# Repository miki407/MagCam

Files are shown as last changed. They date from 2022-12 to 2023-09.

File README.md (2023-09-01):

# MagCam

## Introduction
MagCam is a project that aims to bring a better way of teaching principles of magnetism in a classroom environment. Using this device we hope that students will be more engaged in learning about various topics regarding magnetism as well as electromagnetism. During the process of making this device we looked for a way to improve on the traditional methods of displaying magnetic fields.  

## Comparison with traditional methods

|  Method | Presentation | Versatility | Sensitivity | Polarity | Extra Notes |
|---|---|---|---|---| --- |
| MagCam  | The results can be displayed on a projector | Very versatile in terms of experiments that can be performed | Sensitive to small magnetic fields but limited by the ADC and pre-amp | Has the ability to distinguish between **north** and **south** poles | Can record the data captured
| Iron Dust | Limited number of students can see the results at one time | Number of experiments that can be performed is limited | Only sensitive to strong magnetic fields. Better results can be achieved if particles are suspended in liquid | Doesn't have a way to clearly distinguish between 2 poles | Can stick to the magnets and damage other equipment in the lab |  
| [Flux Detector](https://www.supermagnete.de/eng/school-magnets/flux-detector-small_M-04) | Limited number of students can see the results at one time | Number of experiments that can be performed is sufficient for basic needs | Only sensitive to strong magnetic fields | Doesn't have a way to clearly distinguish between 2 poles |
| Compass array | Limited number of students can see the results at one time |  Very versatile in terms of experiments that can be performed | Sensitive to weak magnetic fields | Has the ability to distinguish between **north** and **south** poles | The device is composed of mechanical compasses and thus needs to be kept horizontal |
| Ferro fluid | Limited number of students can see the results at one time | Number of experiments that can be performed is sufficient for basic needs | Only sensitive to strong magnetic fields | Doesn't have a way to clearly distinguish between 2 poles | Has the possibility to damage other equipment and is hard to clean |
| Virtual demonstration | The results can be displayed on a projector | Any experiment that can be virtually modeled can be performed | The most sensitive option | Has the ability to distinguish between **north** and **south** poles | Requires special training in use of simulation software. It can take a long time for results to be ready. This method doesn't measure magnetic fields and only **simulates** them |

## Basic overview 
MagCam uses 256 hall effect sensors to determine the strength of the magnetic field over a detection area of 110x110 mm. This data is read and sent to the computer for further processing by and esp32 microcontroller. The data is processed and displayed on the computer using an app that was written specifically for this device.

## App
The app reads the values sent by the esp32 and decodes them into individual frames. This data is then calibrated using a baseline value for each sensors. This improves the reading accuracy and allows for less noisy results. In case large gain is used the values received from the device can be averaged. This allows for even less noisy results. 
The app also has a feature that recreates the magnetic field lines from the change in local magnet field strength.
> App is still in development  and more features are planned in the future. There are also plans to improve the gui

## Files
all the files can be found [here](https://github.com/miki407/MagCam)

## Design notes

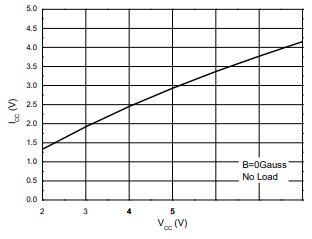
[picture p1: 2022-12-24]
Images/Vcc-Icc_graph_AH49HSC.JPG

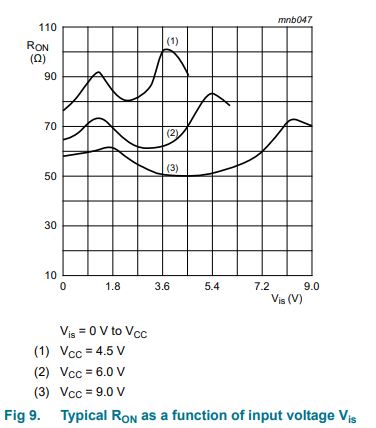
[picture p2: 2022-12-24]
Images/74HC4067_Ron-Vis.JPG

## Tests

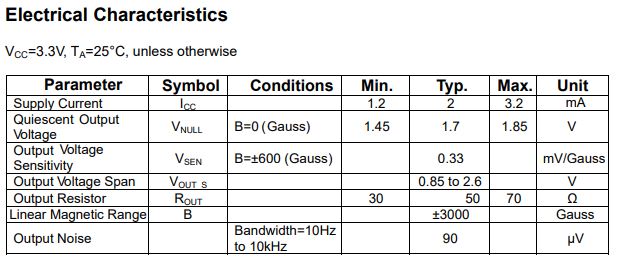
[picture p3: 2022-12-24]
Images/Electrical-characteristic_table.JPG

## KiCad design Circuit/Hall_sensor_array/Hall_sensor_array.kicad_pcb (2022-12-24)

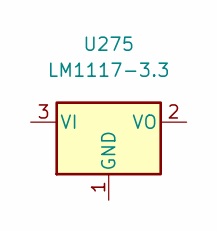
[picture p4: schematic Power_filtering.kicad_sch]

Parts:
U275: LM1117-3.3

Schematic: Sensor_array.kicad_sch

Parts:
C1, C2, C3, C4, C5, C6, C7, C8, C9, C10, C11, C12, C13, C14, C15, C16, C17, C18, C19, C20, C21, C22, C23, C24, C25, C26, C27, C28, C29, C30, C31, C32, C33, C34, C35, C36, C37, C38, C39, C40, C41, C42, C43, C44, C45, C46, C47, C48, C49, C50, C51, C52, C53, C54, C55, C56, C57, C58, C59, C60, C61, C62, C63, C64, C65, C66, C67, C68, C69, C70, C71, C72, C73, C74, C75, C76, C77, C78, C79, C80, C81, C82, C83, C84, C85, C86, C87, C88, C89, C90, C91, C92, C93, C94, C95, C96, C97, C98, C99, C100, C101, C102, C103, C104, C105, C106, C107, C108, C109, C110, C111, C112, C113, C114, C115, C116, C117, C118, C119, C120, C121, C122, C123, C124, C125, C126, C127, C128, C129, C130, C131, C132, C133, C134, C135, C136, C137, C138, C139, C140, C141, C142, C143, C144, C145, C146, C147, C148, C149, C150, C151, C152, C153, C154, C155, C156, C157, C158, C159, C160, C161, C162, C163, C164, C165, C166, C167, C168, C169, C170, C171, C172, C173, C174, C175, C176, C177, C178, C179, C180, C181, C182, C183, C184, C185, C186, C187, C188, C189, C190, C191, C192, C193, C194, C195, C196, C197, C198, C199, C200, C201, C202, C203, C204, C205, C206, C207, C208, C209, C210, C211, C212, C213, C214, C215, C216, C217, C218, C219, C220, C221, C222, C223, C224, C225, C226, C227, C228, C229, C230, C231, C232, C233, C234, C235, C236, C237, C238, C239, C240, C241, C242, C243, C244, C245, C246, C247, C248, C249, C250, C251, C252, C253, C254, C255, C256: 100p; C_0603_1608Metric
U1, U2, U3, U4, U5, U6, U7, U8, U9, U10, U11, U12, U13, U14, U15, U16, U17, U18, U19, U20, U21, U22, U23, U24, U25, U26, U27, U28, U29, U30, U31, U32, U33, U34, U35, U36, U37, U38, U39, U40, U41, U42, U43, U44, U45, U46, U47, U48, U49, U50, U51, U52, U53, U54, U55, U56, U57, U58, U59, U60, U61, U62, U63, U64, U65, U66, U67, U68, U69, U70, U71, U72, U73, U74, U75, U76, U77, U78, U79, U80, U81, U82, U83, U84, U85, U86, U87, U88, U89, U90, U91, U92, U93, U94, U95, U96, U97, U98, U99, U100, U101, U102, U103, U104, U105, U106, U107, U108, U109, U110, U111, U112, U113, U114, U115, U116, U117, U118, U119, U120, U121, U122, U123, U124, U125, U126, U127, U128, U129, U130, U131, U132, U133, U134, U135, U136, U137, U138, U139, U140, U141, U142, U143, U144, U145, U146, U147, U148, U149, U150, U151, U152, U153, U154, U155, U156, U157, U158, U159, U160, U161, U162, U163, U164, U165, U166, U167, U168, U169, U170, U171, U172, U173, U174, U175, U176, U177, U178, U179, U180, U181, U182, U183, U184, U185, U186, U187, U188, U189, U190, U191, U192, U193, U194, U195, U196, U197, U198, U199, U200, U201, U202, U203, U204, U205, U206, U207, U208, U209, U210, U211, U212, U213, U214, U215, U216, U217, U218, U219, U220, U221, U222, U223, U224, U225, U226, U227, U228, U229, U230, U231, U232, U233, U234, U235, U236, U237, U238, U239, U240, U241, U242, U243, U244, U245, U246, U247, U248, U249, U250, U251, U252, U253, U254, U255, U256: AH49HSC; SOT-23-3

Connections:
+3.3V: U1.1 (VDD), U2.1 (VDD), U3.1 (VDD), U4.1 (VDD), U5.1 (VDD), U6.1 (VDD), U7.1 (VDD), U8.1 (VDD), U9.1 (VDD), U10.1 (VDD), U11.1 (VDD), U12.1 (VDD), U13.1 (VDD), U14.1 (VDD), U15.1 (VDD), U16.1 (VDD), U17.1 (VDD), U18.1 (VDD), U19.1 (VDD), U20.1 (VDD), U21.1 (VDD), U22.1 (VDD), U23.1 (VDD), U24.1 (VDD), U25.1 (VDD), U26.1 (VDD), U27.1 (VDD), U28.1 (VDD), U29.1 (VDD), U30.1 (VDD), U31.1 (VDD), U32.1 (VDD), U33.1 (VDD), U34.1 (VDD), U35.1 (VDD), U36.1 (VDD), U37.1 (VDD), U38.1 (VDD), U39.1 (VDD), U40.1 (VDD), U41.1 (VDD), U42.1 (VDD), U43.1 (VDD), U44.1 (VDD), U45.1 (VDD), U46.1 (VDD), U47.1 (VDD), U48.1 (VDD), U49.1 (VDD), U50.1 (VDD), U51.1 (VDD), U52.1 (VDD), U53.1 (VDD), U54.1 (VDD), U55.1 (VDD), U56.1 (VDD), U57.1 (VDD), U58.1 (VDD), U59.1 (VDD), U60.1 (VDD), U61.1 (VDD), U62.1 (VDD), U63.1 (VDD), U64.1 (VDD), U65.1 (VDD), U66.1 (VDD), U67.1 (VDD), U68.1 (VDD), U69.1 (VDD), U70.1 (VDD), U71.1 (VDD), U72.1 (VDD), U73.1 (VDD), U74.1 (VDD), U75.1 (VDD), U76.1 (VDD), U77.1 (VDD), U78.1 (VDD), U79.1 (VDD), U80.1 (VDD), U81.1 (VDD), U82.1 (VDD), U83.1 (VDD), U84.1 (VDD), U85.1 (VDD), U86.1 (VDD), U87.1 (VDD), U88.1 (VDD), U89.1 (VDD), U90.1 (VDD), U91.1 (VDD), U92.1 (VDD), U93.1 (VDD), U94.1 (VDD), U95.1 (VDD), U96.1 (VDD), U97.1 (VDD), U98.1 (VDD), U99.1 (VDD), U100.1 (VDD), U101.1 (VDD), U102.1 (VDD), U103.1 (VDD), U104.1 (VDD), U105.1 (VDD), U106.1 (VDD), U107.1 (VDD), U108.1 (VDD), U109.1 (VDD), U110.1 (VDD), U111.1 (VDD), U112.1 (VDD), U113.1 (VDD), U114.1 (VDD), U115.1 (VDD), U116.1 (VDD), U117.1 (VDD), U118.1 (VDD), U119.1 (VDD), U120.1 (VDD), U121.1 (VDD), U122.1 (VDD), U123.1 (VDD), U124.1 (VDD), U125.1 (VDD), U126.1 (VDD), U127.1 (VDD), U128.1 (VDD), U129.1 (VDD), U130.1 (VDD), U131.1 (VDD), U132.1 (VDD), U133.1 (VDD), U134.1 (VDD), U135.1 (VDD), U136.1 (VDD), U137.1 (VDD), U138.1 (VDD), U139.1 (VDD), U140.1 (VDD), U141.1 (VDD), U142.1 (VDD), U143.1 (VDD), U144.1 (VDD), U145.1 (VDD), U146.1 (VDD), U147.1 (VDD), U148.1 (VDD), U149.1 (VDD), U150.1 (VDD), U151.1 (VDD), U152.1 (VDD), U153.1 (VDD), U154.1 (VDD), U155.1 (VDD), U156.1 (VDD), U157.1 (VDD), U158.1 (VDD), U159.1 (VDD), U160.1 (VDD), U161.1 (VDD), U162.1 (VDD), U163.1 (VDD), U164.1 (VDD), U165.1 (VDD), U166.1 (VDD), U167.1 (VDD), U168.1 (VDD), U169.1 (VDD), U170.1 (VDD), U171.1 (VDD), U172.1 (VDD), U173.1 (VDD), U174.1 (VDD), U175.1 (VDD), U176.1 (VDD), U177.1 (VDD), U178.1 (VDD), U179.1 (VDD), U180.1 (VDD), U181.1 (VDD), U182.1 (VDD), U183.1 (VDD), U184.1 (VDD), U185.1 (VDD), U186.1 (VDD), U187.1 (VDD), U188.1 (VDD), U189.1 (VDD), U190.1 (VDD), U191.1 (VDD), U192.1 (VDD), U193.1 (VDD), U194.1 (VDD), U195.1 (VDD), U196.1 (VDD), U197.1 (VDD), U198.1 (VDD), U199.1 (VDD), U200.1 (VDD), U201.1 (VDD), U202.1 (VDD), U203.1 (VDD), U204.1 (VDD), U205.1 (VDD), U206.1 (VDD), U207.1 (VDD), U208.1 (VDD), U209.1 (VDD), U210.1 (VDD), U211.1 (VDD), U212.1 (VDD), U213.1 (VDD), U214.1 (VDD), U215.1 (VDD), U216.1 (VDD), U217.1 (VDD), U218.1 (VDD), U219.1 (VDD), U220.1 (VDD), U221.1 (VDD), U222.1 (VDD), U223.1 (VDD), U224.1 (VDD), U225.1 (VDD), U226.1 (VDD), U227.1 (VDD), U228.1 (VDD), U229.1 (VDD), U230.1 (VDD), U231.1 (VDD), U232.1 (VDD), U233.1 (VDD), U234.1 (VDD), U235.1 (VDD), U236.1 (VDD), U237.1 (VDD), U238.1 (VDD), U239.1 (VDD), U240.1 (VDD), U241.1 (VDD), U242.1 (VDD), U243.1 (VDD), U244.1 (VDD), U245.1 (VDD), U246.1 (VDD), U247.1 (VDD), U248.1 (VDD), U249.1 (VDD), U250.1 (VDD), U251.1 (VDD), U252.1 (VDD), U253.1 (VDD), U254.1 (VDD), U255.1 (VDD), U256.1 (VDD)
GND: C1.2, C2.2, C3.2, C4.2, C5.2, C6.2, C7.2, C8.2, C9.2, C10.2, C11.2, C12.2, C13.2, C14.2, C15.2, C16.2, C17.2, C18.2, C19.2, C20.2, C21.2, C22.2, C23.2, C24.2, C25.2, C26.2, C27.2, C28.2, C29.2, C30.2, C31.2, C32.2, C33.2, C34.2, C35.2, C36.2, C37.2, C38.2, C39.2, C40.2, C41.2, C42.2, C43.2, C44.2, C45.2, C46.2, C47.2, C48.2, C49.2, C50.2, C51.2, C52.2, C53.2, C54.2, C55.2, C56.2, C57.2, C58.2, C59.2, C60.2, C61.2, C62.2, C63.2, C64.2, C65.2, C66.2, C67.2, C68.2, C69.2, C70.2, C71.2, C72.2, C73.2, C74.2, C75.2, C76.2, C77.2, C78.2, C79.2, C80.2, C81.2, C82.2, C83.2, C84.2, C85.2, C86.2, C87.2, C88.2, C89.2, C90.2, C91.2, C92.2, C93.2, C94.2, C95.2, C96.2, C97.2, C98.2, C99.2, C100.2, C101.2, C102.2, C103.2, C104.2, C105.2, C106.2, C107.2, C108.2, C109.2, C110.2, C111.2, C112.2, C113.2, C114.2, C115.2, C116.2, C117.2, C118.2, C119.2, C120.2, C121.2, C122.2, C123.2, C124.2, C125.2, C126.2, C127.2, C128.2, C129.2, C130.2, C131.2, C132.2, C133.2, C134.2, C135.2, C136.2, C137.2, C138.2, C139.2, C140.2, C141.2, C142.2, C143.2, C144.2, C145.2, C146.2, C147.2, C148.2, C149.2, C150.2, C151.2, C152.2, C153.2, C154.2, C155.2, C156.2, C157.2, C158.2, C159.2, C160.2, C161.2, C162.2, C163.2, C164.2, C165.2, C166.2, C167.2, C168.2, C169.2, C170.2, C171.2, C172.2, C173.2, C174.2, C175.2, C176.2, C177.2, C178.2, C179.2, C180.2, C181.2, C182.2, C183.2, C184.2, C185.2, C186.2, C187.2, C188.2, C189.2, C190.2, C191.2, C192.2, C193.2, C194.2, C195.2, C196.2, C197.2, C198.2, C199.2, C200.2, C201.2, C202.2, C203.2, C204.2, C205.2, C206.2, C207.2, C208.2, C209.2, C210.2, C211.2, C212.2, C213.2, C214.2, C215.2, C216.2, C217.2, C218.2, C219.2, C220.2, C221.2, C222.2, C223.2, C224.2, C225.2, C226.2, C227.2, C228.2, C229.2, C230.2, C231.2, C232.2, C233.2, C234.2, C235.2, C236.2, C237.2, C238.2, C239.2, C240.2, C241.2, C242.2, C243.2, C244.2, C245.2, C246.2, C247.2, C248.2, C249.2, C250.2, C251.2, C252.2, C253.2, C254.2, C255.2, C256.2, U1.3 (GND), U2.3 (GND), U3.3 (GND), U4.3 (GND), U5.3 (GND), U6.3 (GND), U7.3 (GND), U8.3 (GND), U9.3 (GND), U10.3 (GND), U11.3 (GND), U12.3 (GND), U13.3 (GND), U14.3 (GND), U15.3 (GND), U16.3 (GND), U17.3 (GND), U18.3 (GND), U19.3 (GND), U20.3 (GND), U21.3 (GND), U22.3 (GND), U23.3 (GND), U24.3 (GND), U25.3 (GND), U26.3 (GND), U27.3 (GND), U28.3 (GND), U29.3 (GND), U30.3 (GND), U31.3 (GND), U32.3 (GND), U33.3 (GND), U34.3 (GND), U35.3 (GND), U36.3 (GND), U37.3 (GND), U38.3 (GND), U39.3 (GND), U40.3 (GND), U41.3 (GND), U42.3 (GND), U43.3 (GND), U44.3 (GND), U45.3 (GND), U46.3 (GND), U47.3 (GND), U48.3 (GND), U49.3 (GND), U50.3 (GND), U51.3 (GND), U52.3 (GND), U53.3 (GND), U54.3 (GND), U55.3 (GND), U56.3 (GND), U57.3 (GND), U58.3 (GND), U59.3 (GND), U60.3 (GND), U61.3 (GND), U62.3 (GND), U63.3 (GND), U64.3 (GND), U65.3 (GND), U66.3 (GND), U67.3 (GND), U68.3 (GND), U69.3 (GND), U70.3 (GND), U71.3 (GND), U72.3 (GND), U73.3 (GND), U74.3 (GND), U75.3 (GND), U76.3 (GND), U77.3 (GND), U78.3 (GND), U79.3 (GND), U80.3 (GND), U81.3 (GND), U82.3 (GND), U83.3 (GND), U84.3 (GND), U85.3 (GND), U86.3 (GND), U87.3 (GND), U88.3 (GND), U89.3 (GND), U90.3 (GND), U91.3 (GND), U92.3 (GND), U93.3 (GND), U94.3 (GND), U95.3 (GND), U96.3 (GND), U97.3 (GND), U98.3 (GND), U99.3 (GND), U100.3 (GND), U101.3 (GND), U102.3 (GND), U103.3 (GND), U104.3 (GND), U105.3 (GND), U106.3 (GND), U107.3 (GND), U108.3 (GND), U109.3 (GND), U110.3 (GND), U111.3 (GND), U112.3 (GND), U113.3 (GND), U114.3 (GND), U115.3 (GND), U116.3 (GND), U117.3 (GND), U118.3 (GND), U119.3 (GND), U120.3 (GND), U121.3 (GND), U122.3 (GND), U123.3 (GND), U124.3 (GND), U125.3 (GND), U126.3 (GND), U127.3 (GND), U128.3 (GND), U129.3 (GND), U130.3 (GND), U131.3 (GND), U132.3 (GND), U133.3 (GND), U134.3 (GND), U135.3 (GND), U136.3 (GND), U137.3 (GND), U138.3 (GND), U139.3 (GND), U140.3 (GND), U141.3 (GND), U142.3 (GND), U143.3 (GND), U144.3 (GND), U145.3 (GND), U146.3 (GND), U147.3 (GND), U148.3 (GND), U149.3 (GND), U150.3 (GND), U151.3 (GND), U152.3 (GND), U153.3 (GND), U154.3 (GND), U155.3 (GND), U156.3 (GND), U157.3 (GND), U158.3 (GND), U159.3 (GND), U160.3 (GND), U161.3 (GND), U162.3 (GND), U163.3 (GND), U164.3 (GND), U165.3 (GND), U166.3 (GND), U167.3 (GND), U168.3 (GND), U169.3 (GND), U170.3 (GND), U171.3 (GND), U172.3 (GND), U173.3 (GND), U174.3 (GND), U175.3 (GND), U176.3 (GND), U177.3 (GND), U178.3 (GND), U179.3 (GND), U180.3 (GND), U181.3 (GND), U182.3 (GND), U183.3 (GND), U184.3 (GND), U185.3 (GND), U186.3 (GND), U187.3 (GND), U188.3 (GND), U189.3 (GND), U190.3 (GND), U191.3 (GND), U192.3 (GND), U193.3 (GND), U194.3 (GND), U195.3 (GND), U196.3 (GND), U197.3 (GND), U198.3 (GND), U199.3 (GND), U200.3 (GND), U201.3 (GND), U202.3 (GND), U203.3 (GND), U204.3 (GND), U205.3 (GND), U206.3 (GND), U207.3 (GND), U208.3 (GND), U209.3 (GND), U210.3 (GND), U211.3 (GND), U212.3 (GND), U213.3 (GND), U214.3 (GND), U215.3 (GND), U216.3 (GND), U217.3 (GND), U218.3 (GND), U219.3 (GND), U220.3 (GND), U221.3 (GND), U222.3 (GND), U223.3 (GND), U224.3 (GND), U225.3 (GND), U226.3 (GND), U227.3 (GND), U228.3 (GND), U229.3 (GND), U230.3 (GND), U231.3 (GND), U232.3 (GND), U233.3 (GND), U234.3 (GND), U235.3 (GND), U236.3 (GND), U237.3 (GND), U238.3 (GND), U239.3 (GND), U240.3 (GND), U241.3 (GND), U242.3 (GND), U243.3 (GND), U244.3 (GND), U245.3 (GND), U246.3 (GND), U247.3 (GND), U248.3 (GND), U249.3 (GND), U250.3 (GND), U251.3 (GND), U252.3 (GND), U253.3 (GND), U254.3 (GND), U255.3 (GND), U256.3 (GND); also elsewhere on the board
X1Y1: C1.1, U1.2 (OUTPUT); also elsewhere on the board
X1Y2: C2.1, U2.2 (OUTPUT); also elsewhere on the board
X1Y3: C3.1, U3.2 (OUTPUT); also elsewhere on the board
X1Y4: C4.1, U4.2 (OUTPUT); also elsewhere on the board
X1Y5: C5.1, U5.2 (OUTPUT); also elsewhere on the board
X1Y6: C6.1, U6.2 (OUTPUT); also elsewhere on the board
X1Y7: C7.1, U7.2 (OUTPUT); also elsewhere on the board
X1Y8: C8.1, U8.2 (OUTPUT); also elsewhere on the board
X1Y9: C9.1, U9.2 (OUTPUT); also elsewhere on the board
X1Y10: C10.1, U10.2 (OUTPUT); also elsewhere on the board
X1Y11: C11.1, U11.2 (OUTPUT); also elsewhere on the board
X1Y12: C12.1, U12.2 (OUTPUT); also elsewhere on the board
X1Y13: C13.1, U13.2 (OUTPUT); also elsewhere on the board
X1Y14: C14.1, U14.2 (OUTPUT); also elsewhere on the board
X1Y15: C15.1, U15.2 (OUTPUT); also elsewhere on the board
X1Y16: C16.1, U16.2 (OUTPUT); also elsewhere on the board
X2Y1: C17.1, U17.2 (OUTPUT); also elsewhere on the board
X2Y2: C18.1, U18.2 (OUTPUT); also elsewhere on the board
X2Y3: C19.1, U19.2 (OUTPUT); also elsewhere on the board
X2Y4: C20.1, U20.2 (OUTPUT); also elsewhere on the board
X2Y5: C21.1, U21.2 (OUTPUT); also elsewhere on the board
X2Y6: C22.1, U22.2 (OUTPUT); also elsewhere on the board
X2Y7: C23.1, U23.2 (OUTPUT); also elsewhere on the board
X2Y8: C24.1, U24.2 (OUTPUT); also elsewhere on the board
X2Y9: C25.1, U25.2 (OUTPUT); also elsewhere on the board
X2Y10: C26.1, U26.2 (OUTPUT); also elsewhere on the board
X2Y11: C27.1, U27.2 (OUTPUT); also elsewhere on the board
X2Y12: C28.1, U28.2 (OUTPUT); also elsewhere on the board
X2Y13: C29.1, U29.2 (OUTPUT); also elsewhere on the board
X2Y14: C30.1, U30.2 (OUTPUT); also elsewhere on the board
X2Y15: C31.1, U31.2 (OUTPUT); also elsewhere on the board
X2Y16: C32.1, U32.2 (OUTPUT); also elsewhere on the board
X3Y1: C33.1, U33.2 (OUTPUT); also elsewhere on the board
X3Y2: C34.1, U34.2 (OUTPUT); also elsewhere on the board
X3Y3: C35.1, U35.2 (OUTPUT); also elsewhere on the board
X3Y4: C36.1, U36.2 (OUTPUT); also elsewhere on the board
X3Y5: C37.1, U37.2 (OUTPUT); also elsewhere on the board
X3Y6: C38.1, U38.2 (OUTPUT); also elsewhere on the board
X3Y7: C39.1, U39.2 (OUTPUT); also elsewhere on the board
X3Y8: C40.1, U40.2 (OUTPUT); also elsewhere on the board
X3Y9: C41.1, U41.2 (OUTPUT); also elsewhere on the board
X3Y10: C42.1, U42.2 (OUTPUT); also elsewhere on the board
X3Y11: C43.1, U43.2 (OUTPUT); also elsewhere on the board
X3Y12: C44.1, U44.2 (OUTPUT); also elsewhere on the board
X3Y13: C45.1, U45.2 (OUTPUT); also elsewhere on the board
X3Y14: C46.1, U46.2 (OUTPUT); also elsewhere on the board
X3Y15: C47.1, U47.2 (OUTPUT); also elsewhere on the board
X3Y16: C48.1, U48.2 (OUTPUT); also elsewhere on the board
X4Y1: C49.1, U49.2 (OUTPUT); also elsewhere on the board
X4Y2: C50.1, U50.2 (OUTPUT); also elsewhere on the board
X4Y3: C51.1, U51.2 (OUTPUT); also elsewhere on the board
X4Y4: C52.1, U52.2 (OUTPUT); also elsewhere on the board
X4Y5: C53.1, U53.2 (OUTPUT); also elsewhere on the board
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

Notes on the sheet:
With typical current usage of 2mA minimum current of 1.2mA and max current of 3.2mA. The current usage for the whole array should be around 256 * 2mA = 512mA
Hall_Sensor array 16 x 16 array of hall sensors totaling to 256 individual sensors.
Sensor datasheet: https://datasheet.lcsc.com/lcsc/2004231002_PJSEMI-AH49HSC_C510723.pdf

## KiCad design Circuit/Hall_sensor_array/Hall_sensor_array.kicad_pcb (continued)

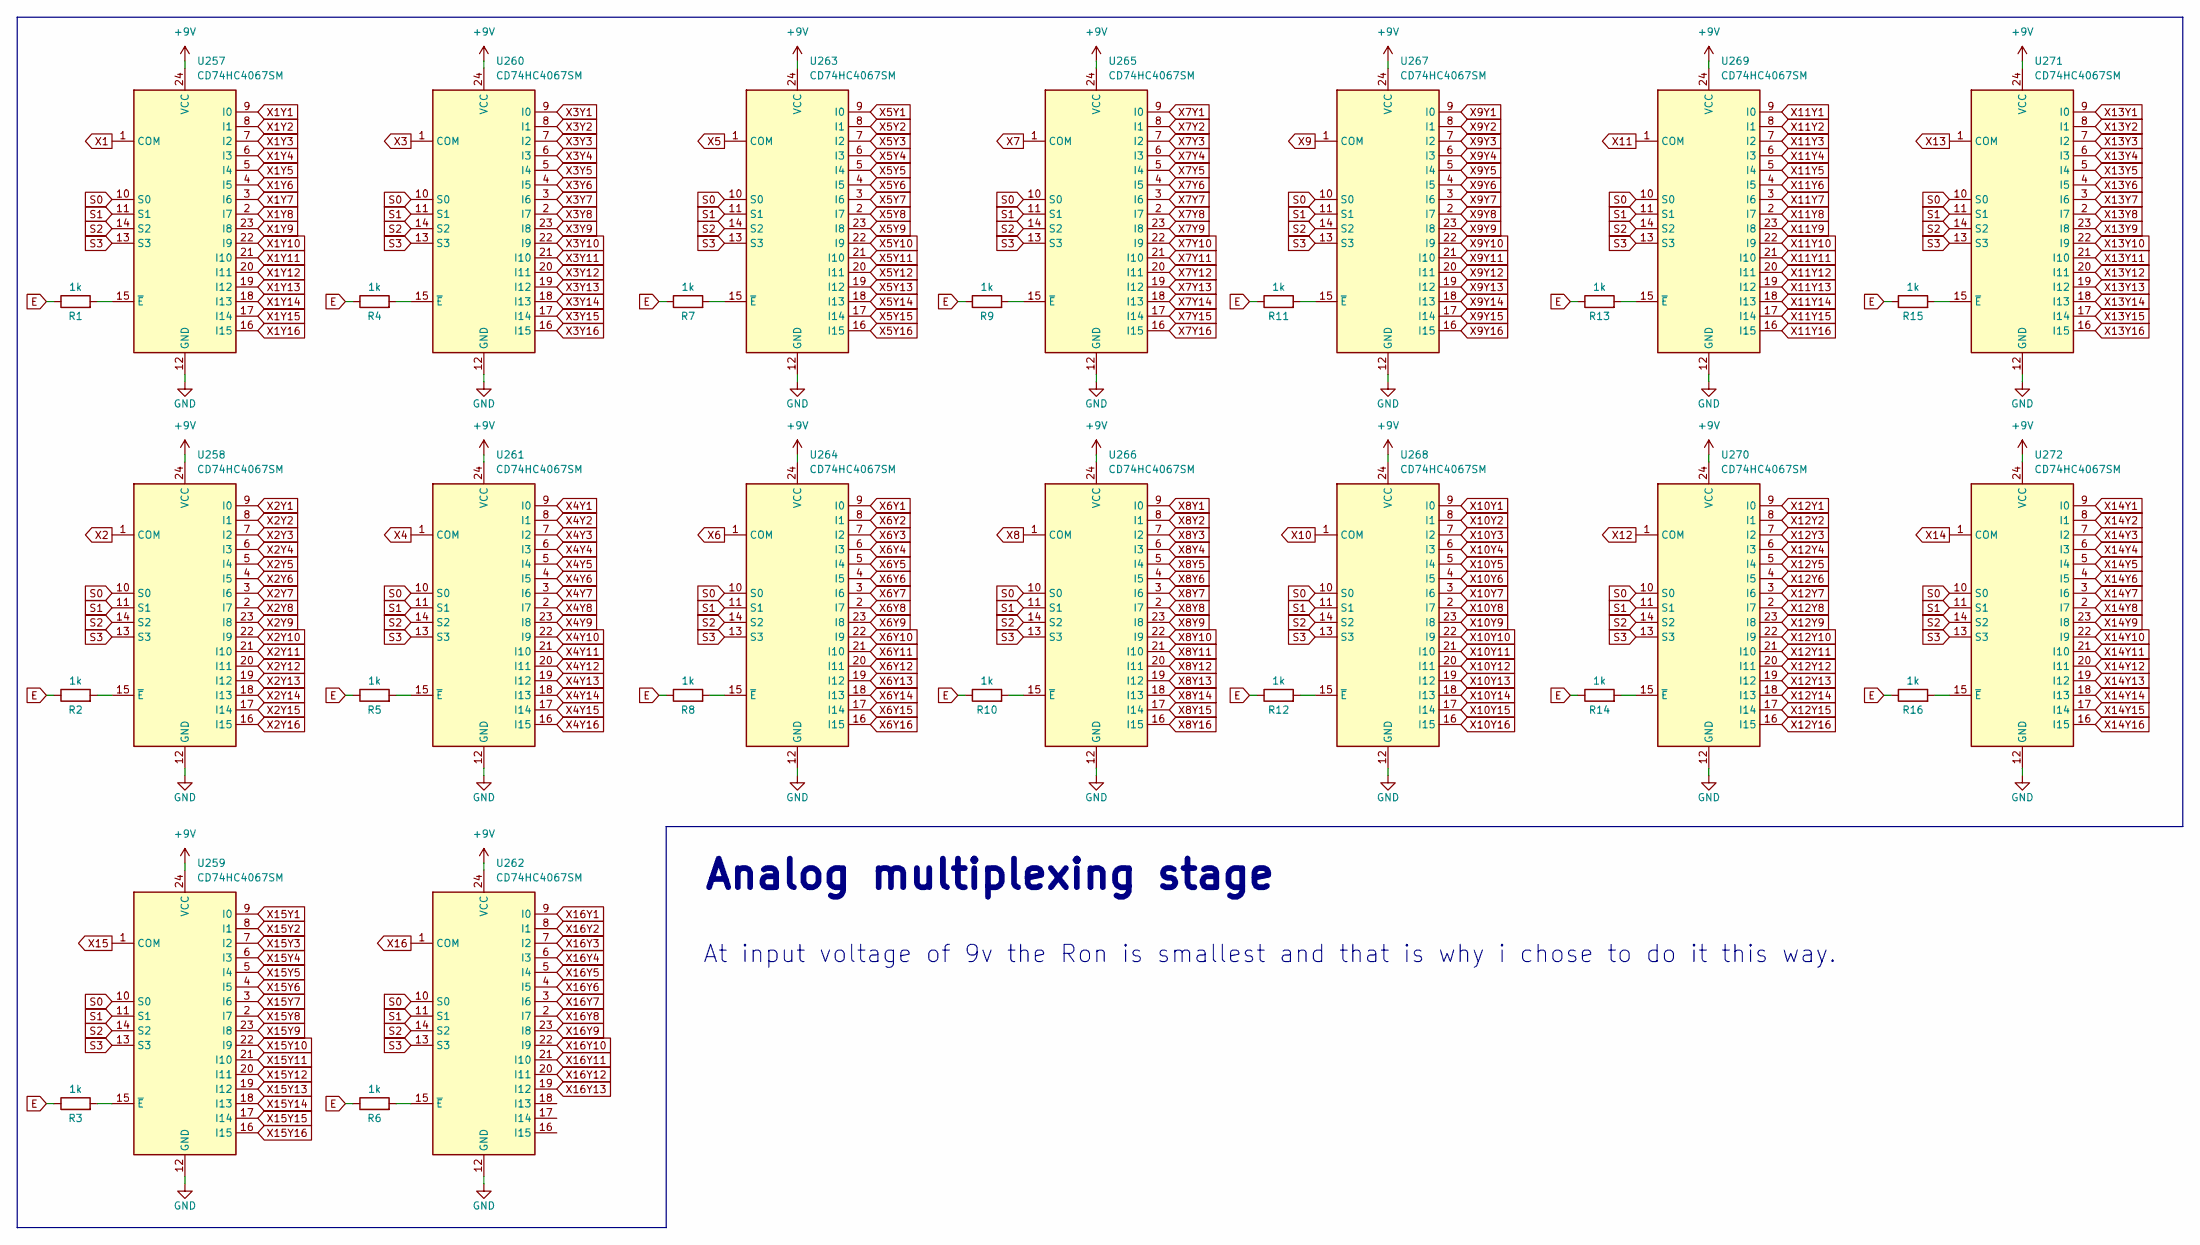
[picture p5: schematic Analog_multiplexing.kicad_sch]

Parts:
R1, R2, R3, R4, R5, R6, R7, R8, R9, R10, R11, R12, R13, R14, R15, R16: 1k
U257, U258, U259, U260, U261, U262, U263, U264, U265, U266, U267, U268, U269, U270, U271, U272: CD74HC4067SM; TSSOP-24_4.4x7.8mm_P0.65mm

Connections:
+9V: U257.24 (VCC), U258.24 (VCC), U259.24 (VCC), U260.24 (VCC), U261.24 (VCC), U262.24 (VCC), U263.24 (VCC), U264.24 (VCC), U265.24 (VCC), U266.24 (VCC), U267.24 (VCC), U268.24 (VCC), U269.24 (VCC), U270.24 (VCC), U271.24 (VCC), U272.24 (VCC)
GND: U257.12 (GND), U258.12 (GND), U259.12 (GND), U260.12 (GND), U261.12 (GND), U262.12 (GND), U263.12 (GND), U264.12 (GND), U265.12 (GND), U266.12 (GND), U267.12 (GND), U268.12 (GND), U269.12 (GND), U270.12 (GND), U271.12 (GND), U272.12 (GND); also elsewhere on the board
unnamed: R1.1, R2.1, R3.1, R4.1, R5.1, R6.1, R7.1, R8.1, R9.1, R10.1, R11.1, R12.1, R13.1, R14.1, R15.1, R16.1
unnamed: R1.2, U257.15 (~E)
unnamed: R2.2, U258.15 (~E)
unnamed: R3.2, U259.15 (~E)
unnamed: R4.2, U260.15 (~E)
unnamed: R5.2, U261.15 (~E)
unnamed: R6.2, U262.15 (~E)
unnamed: R7.2, U263.15 (~E)
unnamed: R8.2, U264.15 (~E)
unnamed: R9.2, U265.15 (~E)
unnamed: R10.2, U266.15 (~E)
unnamed: R11.2, U267.15 (~E)
unnamed: R12.2, U268.15 (~E)
unnamed: R13.2, U269.15 (~E)
unnamed: R14.2, U270.15 (~E)
unnamed: R15.2, U271.15 (~E)
unnamed: R16.2, U272.15 (~E)
S0: U257.10 (S0), U258.10 (S0), U259.10 (S0), U260.10 (S0), U261.10 (S0), U262.10 (S0), U263.10 (S0), U264.10 (S0), U265.10 (S0), U266.10 (S0), U267.10 (S0), U268.10 (S0), U269.10 (S0), U270.10 (S0), U271.10 (S0), U272.10 (S0)
S1: U257.11 (S1), U258.11 (S1), U259.11 (S1), U260.11 (S1), U261.11 (S1), U262.11 (S1), U263.11 (S1), U264.11 (S1), U265.11 (S1), U266.11 (S1), U267.11 (S1), U268.11 (S1), U269.11 (S1), U270.11 (S1), U271.11 (S1), U272.11 (S1)
S2: U257.14 (S2), U258.14 (S2), U259.14 (S2), U260.14 (S2), U261.14 (S2), U262.14 (S2), U263.14 (S2), U264.14 (S2), U265.14 (S2), U266.14 (S2), U267.14 (S2), U268.14 (S2), U269.14 (S2), U270.14 (S2), U271.14 (S2), U272.14 (S2)
S3: U257.13 (S3), U258.13 (S3), U259.13 (S3), U260.13 (S3), U261.13 (S3), U262.13 (S3), U263.13 (S3), U264.13 (S3), U265.13 (S3), U266.13 (S3), U267.13 (S3), U268.13 (S3), U269.13 (S3), U270.13 (S3), U271.13 (S3), U272.13 (S3)
X1: U257.1 (COM)
X1Y1: U257.9 (I0); also elsewhere on the board
X1Y2: U257.8 (I1); also elsewhere on the board
X1Y3: U257.7 (I2); also elsewhere on the board
X1Y4: U257.6 (I3); also elsewhere on the board
X1Y5: U257.5 (I4); also elsewhere on the board
X1Y6: U257.4 (I5); also elsewhere on the board
X1Y7: U257.3 (I6); also elsewhere on the board
X1Y8: U257.2 (I7); also elsewhere on the board
X1Y9: U257.23 (I8); also elsewhere on the board
X1Y10: U257.22 (I9); also elsewhere on the board
X1Y11: U257.21 (I10); also elsewhere on the board
X1Y12: U257.20 (I11); also elsewhere on the board
X1Y13: U257.19 (I12); also elsewhere on the board
X1Y14: U257.18 (I13); also elsewhere on the board
X1Y15: U257.17 (I14); also elsewhere on the board
X1Y16: U257.16 (I15); also elsewhere on the board
X2: U258.1 (COM)
X2Y1: U258.9 (I0); also elsewhere on the board
X2Y2: U258.8 (I1); also elsewhere on the board
X2Y3: U258.7 (I2); also elsewhere on the board
X2Y4: U258.6 (I3); also elsewhere on the board
X2Y5: U258.5 (I4); also elsewhere on the board
X2Y6: U258.4 (I5); also elsewhere on the board
X2Y7: U258.3 (I6); also elsewhere on the board
X2Y8: U258.2 (I7); also elsewhere on the board
X2Y9: U258.23 (I8); also elsewhere on the board
X2Y10: U258.22 (I9); also elsewhere on the board
X2Y11: U258.21 (I10); also elsewhere on the board
X2Y12: U258.20 (I11); also elsewhere on the board
X2Y13: U258.19 (I12); also elsewhere on the board
X2Y14: U258.18 (I13); also elsewhere on the board
X2Y15: U258.17 (I14); also elsewhere on the board
X2Y16: U258.16 (I15); also elsewhere on the board
X3: U260.1 (COM)
X3Y1: U260.9 (I0); also elsewhere on the board
X3Y2: U260.8 (I1); also elsewhere on the board
X3Y3: U260.7 (I2); also elsewhere on the board
X3Y4: U260.6 (I3); also elsewhere on the board
X3Y5: U260.5 (I4); also elsewhere on the board
X3Y6: U260.4 (I5); also elsewhere on the board
X3Y7: U260.3 (I6); also elsewhere on the board
X3Y8: U260.2 (I7); also elsewhere on the board
X3Y9: U260.23 (I8); also elsewhere on the board
X3Y10: U260.22 (I9); also elsewhere on the board
X3Y11: U260.21 (I10); also elsewhere on the board
X3Y12: U260.20 (I11); also elsewhere on the board
X3Y13: U260.19 (I12); also elsewhere on the board
X3Y14: U260.18 (I13); also elsewhere on the board
X3Y15: U260.17 (I14); also elsewhere on the board
X3Y16: U260.16 (I15); also elsewhere on the board
X4: U261.1 (COM)
X4Y1: U261.9 (I0); also elsewhere on the board
X4Y2: U261.8 (I1); also elsewhere on the board
X4Y3: U261.7 (I2); also elsewhere on the board
X4Y4: U261.6 (I3); also elsewhere on the board
X4Y5: U261.5 (I4); also elsewhere on the board
X4Y6: U261.4 (I5); also elsewhere on the board
X4Y7: U261.3 (I6); also elsewhere on the board
X4Y8: U261.2 (I7); also elsewhere on the board
X4Y9: U261.23 (I8); also elsewhere on the board
X4Y10: U261.22 (I9); also elsewhere on the board
X4Y11: U261.21 (I10); also elsewhere on the board
X4Y12: U261.20 (I11); also elsewhere on the board
X4Y13: U261.19 (I12); also elsewhere on the board
X4Y14: U261.18 (I13); also elsewhere on the board
X4Y15: U261.17 (I14); also elsewhere on the board
X4Y16: U261.16 (I15); also elsewhere on the board
X5: U263.1 (COM)
X5Y1: U263.9 (I0); also elsewhere on the board
X5Y2: U263.8 (I1); also elsewhere on the board
X5Y3: U263.7 (I2); also elsewhere on the board
X5Y4: U263.6 (I3); also elsewhere on the board
X5Y5: U263.5 (I4); also elsewhere on the board
X5Y6: U263.4 (I5); also elsewhere on the board
X5Y7: U263.3 (I6); also elsewhere on the board
X5Y8: U263.2 (I7); also elsewhere on the board
X5Y9: U263.23 (I8); also elsewhere on the board
X5Y10: U263.22 (I9); also elsewhere on the board
X5Y11: U263.21 (I10); also elsewhere on the board
X5Y12: U263.20 (I11); also elsewhere on the board
X5Y13: U263.19 (I12); also elsewhere on the board
X5Y14: U263.18 (I13); also elsewhere on the board
X5Y15: U263.17 (I14); also elsewhere on the board
X5Y16: U263.16 (I15); also elsewhere on the board
X6: U264.1 (COM)
X6Y1: U264.9 (I0); also elsewhere on the board
X6Y2: U264.8 (I1); also elsewhere on the board
X6Y3: U264.7 (I2); also elsewhere on the board
X6Y4: U264.6 (I3); also elsewhere on the board
X6Y5: U264.5 (I4); also elsewhere on the board
X6Y6: U264.4 (I5); also elsewhere on the board
X6Y7: U264.3 (I6); also elsewhere on the board
X6Y8: U264.2 (I7); also elsewhere on the board
X6Y9: U264.23 (I8); also elsewhere on the board
X6Y10: U264.22 (I9); also elsewhere on the board
X6Y11: U264.21 (I10); also elsewhere on the board
X6Y12: U264.20 (I11); also elsewhere on the board
X6Y13: U264.19 (I12); also elsewhere on the board
X6Y14: U264.18 (I13); also elsewhere on the board
X6Y15: U264.17 (I14); also elsewhere on the board
X6Y16: U264.16 (I15); also elsewhere on the board
X7: U265.1 (COM)
X7Y1: U265.9 (I0); also elsewhere on the board
X7Y2: U265.8 (I1); also elsewhere on the board
X7Y3: U265.7 (I2); also elsewhere on the board
X7Y4: U265.6 (I3); also elsewhere on the board
X7Y5: U265.5 (I4); also elsewhere on the board
X7Y6: U265.4 (I5); also elsewhere on the board
X7Y7: U265.3 (I6); also elsewhere on the board
X7Y8: U265.2 (I7); also elsewhere on the board
X7Y9: U265.23 (I8); also elsewhere on the board
X7Y10: U265.22 (I9); also elsewhere on the board
X7Y11: U265.21 (I10); also elsewhere on the board
X7Y12: U265.20 (I11); also elsewhere on the board
X7Y13: U265.19 (I12); also elsewhere on the board
X7Y14: U265.18 (I13); also elsewhere on the board
X7Y15: U265.17 (I14); also elsewhere on the board
X7Y16: U265.16 (I15); also elsewhere on the board
X8: U266.1 (COM)
X8Y1: U266.9 (I0); also elsewhere on the board
X8Y2: U266.8 (I1); also elsewhere on the board
X8Y3: U266.7 (I2); also elsewhere on the board
X8Y4: U266.6 (I3); also elsewhere on the board
X8Y5: U266.5 (I4); also elsewhere on the board
X8Y6: U266.4 (I5); also elsewhere on the board
X8Y7: U266.3 (I6); also elsewhere on the board
X8Y8: U266.2 (I7); also elsewhere on the board
X8Y9: U266.23 (I8); also elsewhere on the board
X8Y10: U266.22 (I9); also elsewhere on the board
X8Y11: U266.21 (I10); also elsewhere on the board
X8Y12: U266.20 (I11); also elsewhere on the board
X8Y13: U266.19 (I12); also elsewhere on the board
X8Y14: U266.18 (I13); also elsewhere on the board
X8Y15: U266.17 (I14); also elsewhere on the board
X8Y16: U266.16 (I15); also elsewhere on the board
X9: U267.1 (COM)
X9Y1: U267.9 (I0); also elsewhere on the board
X9Y2: U267.8 (I1); also elsewhere on the board
X9Y3: U267.7 (I2); also elsewhere on the board
X9Y4: U267.6 (I3); also elsewhere on the board
X9Y5: U267.5 (I4); also elsewhere on the board
X9Y6: U267.4 (I5); also elsewhere on the board
X9Y7: U267.3 (I6); also elsewhere on the board
X9Y8: U267.2 (I7); also elsewhere on the board
X9Y9: U267.23 (I8); also elsewhere on the board
X9Y10: U267.22 (I9); also elsewhere on the board
X9Y11: U267.21 (I10); also elsewhere on the board
X9Y12: U267.20 (I11); also elsewhere on the board
X9Y13: U267.19 (I12); also elsewhere on the board
X9Y14: U267.18 (I13); also elsewhere on the board
X9Y15: U267.17 (I14); also elsewhere on the board
X9Y16: U267.16 (I15); also elsewhere on the board
X10: U268.1 (COM)
X10Y1: U268.9 (I0); also elsewhere on the board
X10Y2: U268.8 (I1); also elsewhere on the board
X10Y3: U268.7 (I2); also elsewhere on the board
X10Y4: U268.6 (I3); also elsewhere on the board
X10Y5: U268.5 (I4); also elsewhere on the board
X10Y6: U268.4 (I5); also elsewhere on the board
X10Y7: U268.3 (I6); also elsewhere on the board
X10Y8: U268.2 (I7); also elsewhere on the board
X10Y9: U268.23 (I8); also elsewhere on the board
X10Y10: U268.22 (I9); also elsewhere on the board
X10Y11: U268.21 (I10); also elsewhere on the board
X10Y12: U268.20 (I11); also elsewhere on the board
X10Y13: U268.19 (I12); also elsewhere on the board
X10Y14: U268.18 (I13); also elsewhere on the board
X10Y15: U268.17 (I14); also elsewhere on the board
X10Y16: U268.16 (I15); also elsewhere on the board
X11: U269.1 (COM)
X11Y1: U269.9 (I0); also elsewhere on the board
X11Y2: U269.8 (I1); also elsewhere on the board
X11Y3: U269.7 (I2); also elsewhere on the board
X11Y4: U269.6 (I3); also elsewhere on the board
X11Y5: U269.5 (I4); also elsewhere on the board
X11Y6: U269.4 (I5); also elsewhere on the board
X11Y7: U269.3 (I6); also elsewhere on the board
X11Y8: U269.2 (I7); also elsewhere on the board
X11Y9: U269.23 (I8); also elsewhere on the board
X11Y10: U269.22 (I9); also elsewhere on the board
X11Y11: U269.21 (I10); also elsewhere on the board
X11Y12: U269.20 (I11); also elsewhere on the board
X11Y13: U269.19 (I12); also elsewhere on the board
X11Y14: U269.18 (I13); also elsewhere on the board
X11Y15: U269.17 (I14); also elsewhere on the board
X11Y16: U269.16 (I15); also elsewhere on the board
X12: U270.1 (COM)
X12Y1: U270.9 (I0); also elsewhere on the board
X12Y2: U270.8 (I1); also elsewhere on the board
X12Y3: U270.7 (I2); also elsewhere on the board
X12Y4: U270.6 (I3); also elsewhere on the board
X12Y5: U270.5 (I4); also elsewhere on the board
X12Y6: U270.4 (I5); also elsewhere on the board
X12Y7: U270.3 (I6); also elsewhere on the board
X12Y8: U270.2 (I7); also elsewhere on the board
X12Y9: U270.23 (I8); also elsewhere on the board
X12Y10: U270.22 (I9); also elsewhere on the board
X12Y11: U270.21 (I10); also elsewhere on the board
X12Y12: U270.20 (I11); also elsewhere on the board
X12Y13: U270.19 (I12); also elsewhere on the board
X12Y14: U270.18 (I13); also elsewhere on the board
X12Y15: U270.17 (I14); also elsewhere on the board
X12Y16: U270.16 (I15); also elsewhere on the board
X13: U271.1 (COM)
X13Y1: U271.9 (I0); also elsewhere on the board
X13Y2: U271.8 (I1); also elsewhere on the board
X13Y3: U271.7 (I2); also elsewhere on the board
X13Y4: U271.6 (I3); also elsewhere on the board
X13Y5: U271.5 (I4); also elsewhere on the board
X13Y6: U271.4 (I5); also elsewhere on the board
X13Y7: U271.3 (I6); also elsewhere on the board
X13Y8: U271.2 (I7); also elsewhere on the board
X13Y9: U271.23 (I8); also elsewhere on the board
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

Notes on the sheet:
At input voltage of 9v the Ron is smallest and that is why i chose to do it this way.
Analog multiplexing stage

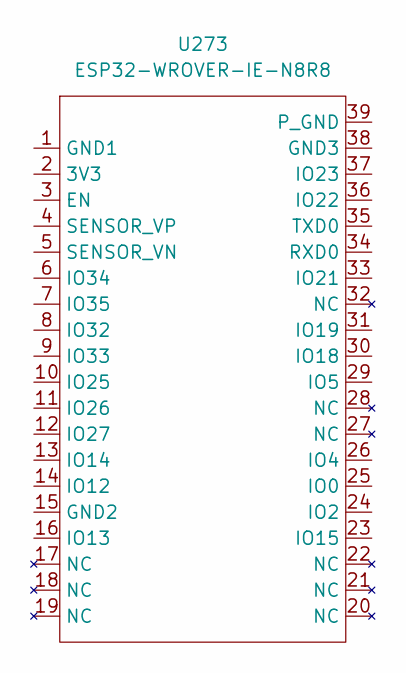
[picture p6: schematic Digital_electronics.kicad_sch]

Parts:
U273: ESP32-WROVER-IE-N8R8

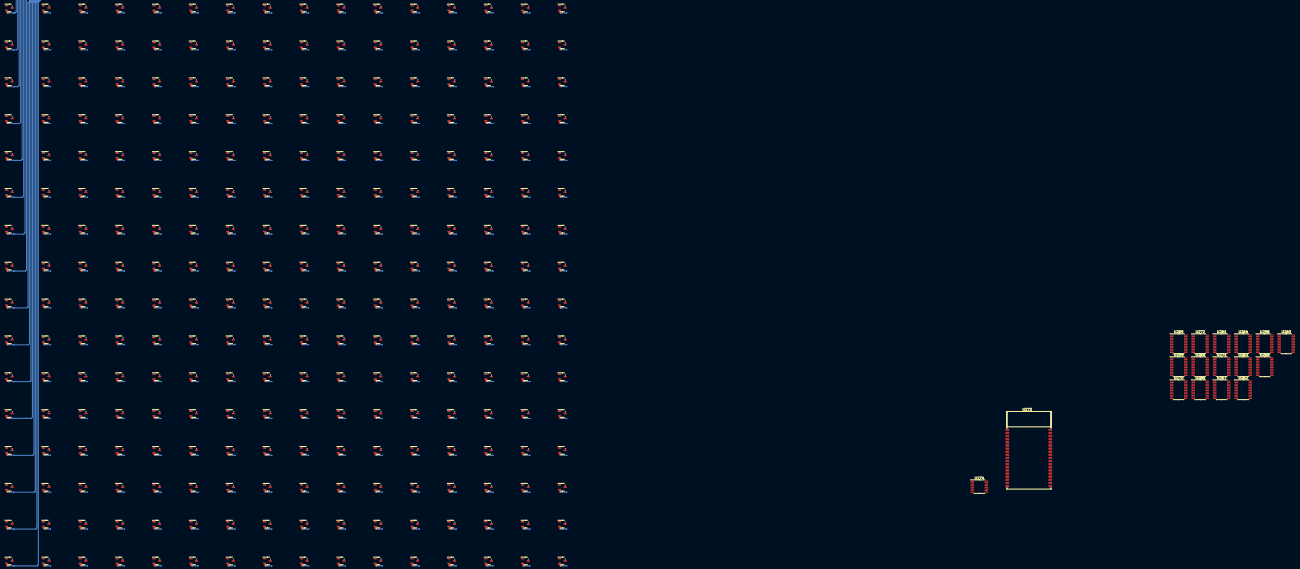
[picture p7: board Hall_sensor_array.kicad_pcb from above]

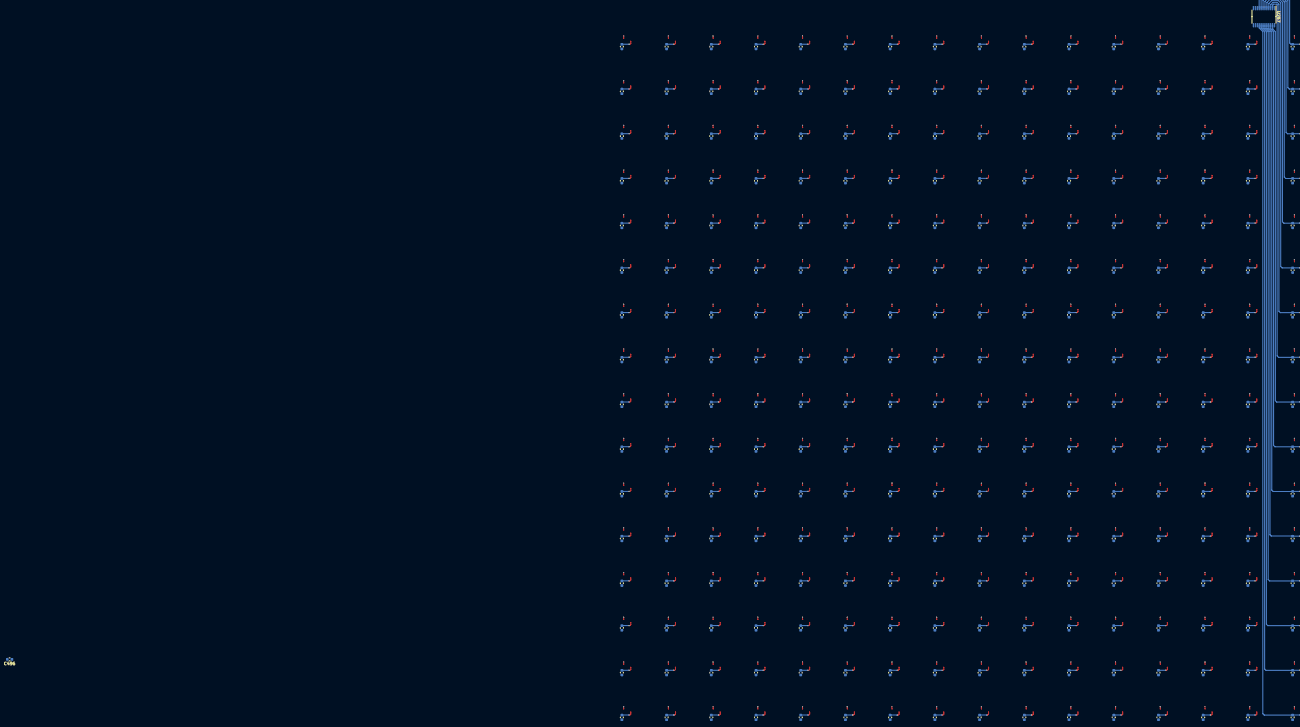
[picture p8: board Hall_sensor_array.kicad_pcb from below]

Board: 2 copper layers, 531 parts (258 on the bottom side), 263 nets.

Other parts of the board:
C496: 10n; C_0603_1608Metric
U274: ADS7830; TSSOP-16_4.4x5mm_P0.65mm

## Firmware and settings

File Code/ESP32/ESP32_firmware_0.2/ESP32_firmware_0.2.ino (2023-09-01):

//  ESP32 Firmware for MagCam v0.2
//
//  8/25/2023 writen by Milos MIlievic
//
//  This firmware reads the date from an array of 256 hall effect sensors. This data is then transmited using Serial at 921600 BaudRate to a computer running the desktop application

#include "adc.h"        // include libreries

#define FCOUNT GPIO_NUM_33  // Pin number assigned to the binary counter for setting the read adress
#define AIN GPIO_NUM_32     // Pin number assigned to the output of the analog multiplexers 
#define FRESET GPIO_NUM_27  // Pin number assigned to the binary counter reset pin

#define DEVIDER 800   // These values determine the the frame rate of the module. This frame rate is calculated using the following formula:
#define COUNTER 4100  // Frame Rate = 80000000 / (DEVIDER * COUNTER)             24.0038406 fraes/ second

#define FRAMES_BEFORE_RESET 64 // The number of frames after witch the binary counter is reset

#define BUFFER_SIZE 512 // Value determening the number of elements in the array outBuffer

uint8_t *outBuffer = (uint8_t *)malloc(sizeof(uint8_t) * BUFFER_SIZE); // Creating an uint8_t array with BUFFER_SIZE elements

TaskHandle_t Task1; // Handle for setting up a task on a diffrent core for multithreading

hw_timer_t *My_timer = NULL; // Timer that determanes the framerate

bool state = false; // Global variables for keeping track of the state of the frame and current frame count
uint8_t frame = 0;

void IRAM_ATTR onTimer() { // Function ran everytime the timer triggers
  if (frame == 64) {       // Check if the current frame count equals 64 and reset the counter if that is the case. This is done as a preventative measure in case any bits are skipped
    gpio_set_level(FRESET, 1);
    delayMicroseconds(5);
    gpio_set_level(FRESET, 0);
    frame = 0;              // Reset the frame counter to 0
  }
  for (uint8_t x = 0; x < 16; x++) {  // For loop to go trough all the column
    adc1_get_raw(ADC1_CHANNEL_4); // Disriguard 2 readings on the start of each column. This is done to increase the accuracy of the SAR ADCs
    adc1_get_raw(ADC1_CHANNEL_4);
    for (uint8_t y = 0; y < 16; y++) { // For loop to go trought all the column
      gpio_set_level(FCOUNT, 1);   // Change state of the output pin FCOUNT to hight
      uint16_t buf = adc1_get_raw(ADC1_CHANNEL_4);   // Store the current ADC reading in memory
      gpio_set_level(FCOUNT, 0);  // Change state of output pin FCOUNT to low
      //                             ADC data      ADC Reading             empty    ADC MSB         empty   ADC LSB
      outBuffer[(x * 16 + y) * 2] = (uint8_t)((buf & 0x0FC0) >> 6); // Convert the read data from |_ _ _ _ | _ _ _ _ _ _ _ _ _ _ |   to  |_ _ | _ _ _ _ _ _ | and |_ _ |_ _ _ _ _ _|
      outBuffer[(x * 16 + y) * 2 + 1] = (uint8_t)(buf & 0x003F); //                                  4bits          12bits               2bits     6bits          2bits    6bits
      //delayMicroseconds(1); // delay to give digital pins time to change state
    }
  }
  frame++; // Incrament frame counter
  state = true; // Change state to indicate frame is done
}

void setup() {

  gpio_set_direction(FCOUNT, GPIO_MODE_OUTPUT);  // Set gpio pins as outputs or inputs
  gpio_set_direction(FRESET, GPIO_MODE_OUTPUT);
  pinMode(AIN, INPUT);

  adc_power_acquire();                           // Initilize the ADC
  adc1_config_channel_atten(ADC1_CHANNEL_4, ADC_ATTEN_11db);
  adc1_config_width( ADC_WIDTH_12Bit);
  adc_set_clk_div(1);

  Serial.begin(921600);   // Serial initilization


  My_timer = timerBegin(0, DEVIDER, true);      // Setting up the timer
  timerAttachInterrupt(My_timer, &onTimer, true);
  timerAlarmWrite(My_timer, COUNTER, true);
  timerAlarmEnable(My_timer);

  // create a task that will be executed in the Task1code() function, with priority 0 and executed on core 0
  xTaskCreatePinnedToCore(
    Task1code,   /* Task function. */
    "Task1",     /* name of task. */
    100000,       /* Stack size of task */
    NULL,        /* parameter of the task */
    0,           /* priority of the task */
    &Task1,      /* Task handle to keep track of created task */
    0);          /* pin task to core 0 */


  gpio_set_level(FRESET, 1); // Reset the binary counter on startup
  delayMicroseconds(5);
  gpio_set_level(FRESET, 0);

}

void Task1code( void * pvParameters ) { //Code running on Core 0
  for (;;) {  //Loop
    if (state) {  //if the frame is finished reading
      state = false;  //change the state of the frame
      for (uint16_t n = 0; n < BUFFER_SIZE; n++) {  //For loop to go trough all the values
        Serial.write(outBuffer[n]);     //output the frame to serial
      }
    }
    else if (!state) {
      __asm("nop");
    }
  }
}
void loop() {
  //UNUSED
}

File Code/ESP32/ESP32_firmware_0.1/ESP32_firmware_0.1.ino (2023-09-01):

#include "adc.h"
#include "driver/rtc_io.h"

#define FCOUNT 33
#define AIN 32

#define DEVIDER 700
#define COUNTER 3700

#define BUFFER_SIZE 256

TaskHandle_t Task1;

hw_timer_t *My_timer = NULL;

uint16_t *buffer = (uint16_t *)malloc(sizeof(uint16_t) * BUFFER_SIZE);
uint8_t *outBuffer = (uint8_t *)malloc(sizeof(uint8_t) * BUFFER_SIZE * 2);

int counter = 0;
int frame = 0;

void IRAM_ATTR onTimer() {
  if (frame > 31) {
    gpio_set_level(GPIO_NUM_27, 1);
    delayMicroseconds(15);
    gpio_set_level(GPIO_NUM_27, 0);
    delayMicroseconds(15);
    frame = 0;
  }
  frame++;
  adc1_get_raw(ADC1_CHANNEL_4);
  adc1_get_raw(ADC1_CHANNEL_4);
  for (int i = 0; i != 256; i++) {
    gpio_set_level(GPIO_NUM_33, 1);
    //delayMicroseconds(1);
    buffer[i] = adc1_get_raw(ADC1_CHANNEL_4);
    gpio_set_level(GPIO_NUM_33, 0);
    delayMicroseconds(5);
  }
  counter = 256;
}

void setup() {
  //pin mode
  gpio_set_direction(GPIO_NUM_33, GPIO_MODE_OUTPUT);
  gpio_set_pull_mode(GPIO_NUM_33, GPIO_PULLDOWN_ONLY);
  //gpio_set_drive_capability(GPIO_NUM_33, GPIO_DRIVE_CAP_MAX);
  gpio_set_direction(GPIO_NUM_27, GPIO_MODE_OUTPUT);
  gpio_set_pull_mode(GPIO_NUM_27, GPIO_PULLDOWN_ONLY);
  //gpio_set_drive_capability(GPIO_NUM_25, GPIO_DRIVE_CAP_3);
  //pinMode(FCOUNT, OUTPUT);
  pinMode(AIN, INPUT);

  gpio_set_level(GPIO_NUM_27, 1);
  delayMicroseconds(5);
  gpio_set_level(GPIO_NUM_27, 0);

  adc_power_acquire();
  adc1_config_channel_atten(ADC1_CHANNEL_4, ADC_ATTEN_11db);
  adc1_config_width(ADC_WIDTH_12Bit);
  adc_set_clk_div(0);
  // timer setup
  Serial.begin(921600);
  My_timer = timerBegin(0, DEVIDER, true);
  timerAttachInterrupt(My_timer, &onTimer, true);
  timerAlarmWrite(My_timer, COUNTER, true);
  timerAlarmEnable(My_timer);  //Just Enable

  //create a task that will be executed in the Task1code() function, with priority 1 and executed on core 0
  xTaskCreatePinnedToCore(
    Task1code, /* Task function. */
    "Task1",   /* name of task. */
    100000,    /* Stack size of task */
    NULL,      /* parameter of the task */
    0,         /* priority of the task */
    &Task1,    /* Task handle to keep track of created task */
    0);        /* pin task to core 0 */
}

void Task1code(void *pvParameters) {
  for (;;) {
    if (counter == 256) {
      //for (uint16_t n = 0; n < 256; n++) {
      //outBuffer[n * 2] = (uint8_t)((buffer[n] & 0x0FC0) >> 6);
      //outBuffer[n * 2 + 1] = (uint8_t)(buffer[n] & 0x003F);
      //}
      counter = 0;
      uint16_t n;
      for (n = 0; n != 256; n++) {
        //Serial.write(outBuffer[n]);
        Serial.write((uint8_t)((buffer[n] & 0x0FC0) >> 6));
        __asm("nop");
        Serial.write((uint8_t)(buffer[n] & 0x003F));
      }
    } else if (counter > 256) {
      Serial.printf("\n Skipped frame %d\n", counter);
    }
  }
}
void loop() {
}

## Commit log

2022-12-23 Added Circuit(unfinished)
    I just strated learing how to use KiCAD. This circuit will take some time to finish.
    The PCB files are also inside
    [Hall_sensor_array.kicad_pcb, Hall_sensor_array.kicad_sch]
2022-12-24 Updated circuit(work in progress)
    [ADC.kicad_sch, Analog_multiplexing.kicad_sch, Digital_electronics.kicad_sch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]
2022-12-31 Updated circuit
    Added binary counter for selecting analog multiplexer address
    [ADC.kicad_sch, Analog_multiplexing.kicad_sch, Digital_electronics.kicad_sch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]
2023-01-23 Big progress on the project
    [Analog_multiplexing.kicad_sch, Digital_electronics.kicad_sch, Hall_sensor_array.kicad_sch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]
2023-02-02 Updated PCB/Fixed Curcuit
    [ADC.kicad_sch, Analog_multiplexing.kicad_sch, Digital_electronics.kicad_sch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]
2023-02-21 latest update
    [Download_STP_WE-HCFT-2818B (rev1).stp]
2023-08-09 Major update! New pcb
    i did some work
    [Analog_multiplexing.kicad_sch, Digital_electronics.kicad_sch, Hall_sensor_array.kicad_sch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]
2023-09-01 V0.1a
    First release of the version 0.1 of this project.
    [Case.stp, Download_STP_WE-HCFT-2818B (rev1).stp, ESP32-WROVER-I--3DModel-STEP-56544.STEP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]
2023-09-01 V0.1b
    - Updated README
    - Fixed
    > Bug where pause feature didn't work as intended
    > Bug where reset was inverted in Firmware V0.2
    [ESP32_firmware_0.2.ino]
